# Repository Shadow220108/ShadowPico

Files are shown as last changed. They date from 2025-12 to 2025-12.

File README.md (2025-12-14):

# SHADOW PICO  
It is a handheld device that works on Raspberry Pi Pico

# Model  
This is the final look of the device  
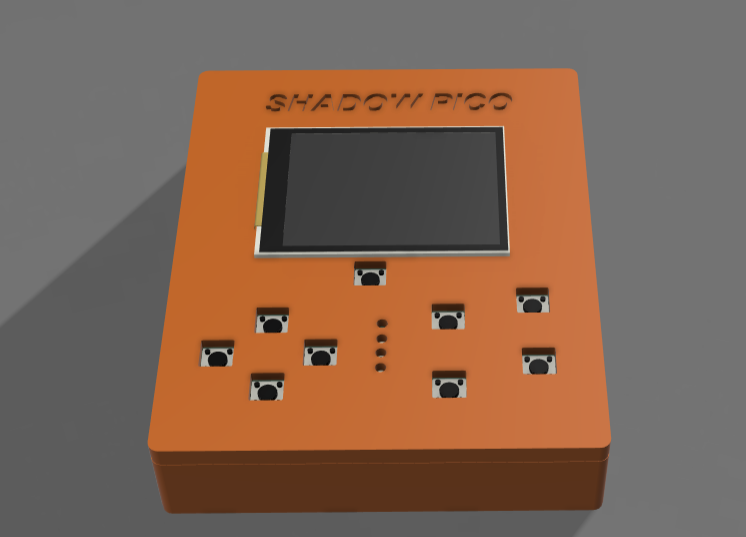
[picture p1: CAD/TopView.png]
TopView
  

I have added a small hole on the side for usb  
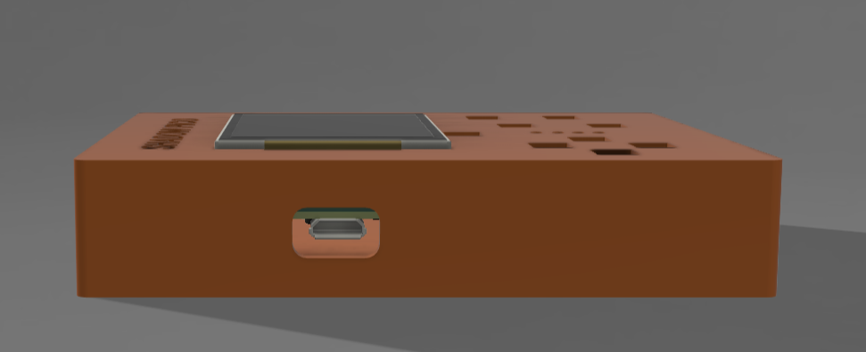
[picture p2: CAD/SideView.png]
SideView
  

On the front there are 3 holes for the SD Card , External Connector and a Slide switch for power  
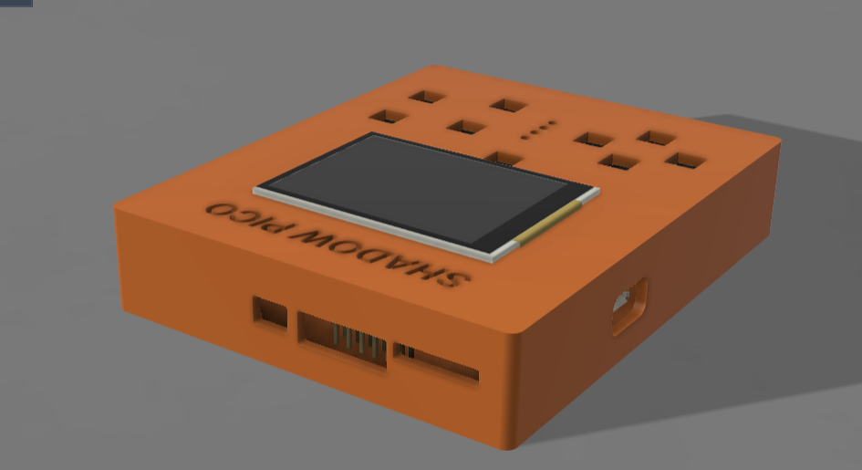
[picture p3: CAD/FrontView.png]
FrontView
  

I have used ridges to attach the bottom case to the top case!  
Bottom Case :  
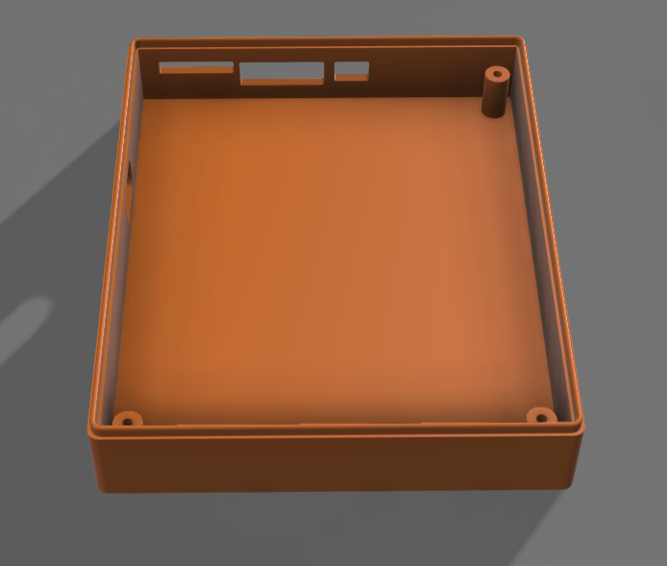
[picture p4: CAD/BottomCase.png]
BottomCase
  
Top Case :  
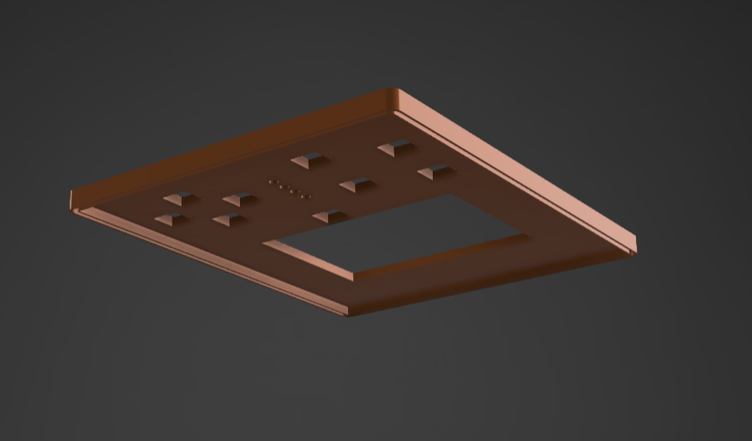
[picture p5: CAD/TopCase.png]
TopCase
  

# PCB  
This is the PCB ( ground pour is hidden )  
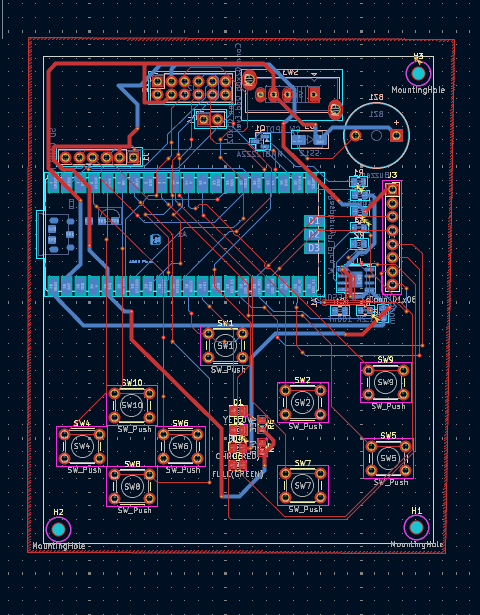
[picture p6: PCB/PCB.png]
PCB
  

And here are the schematics!  
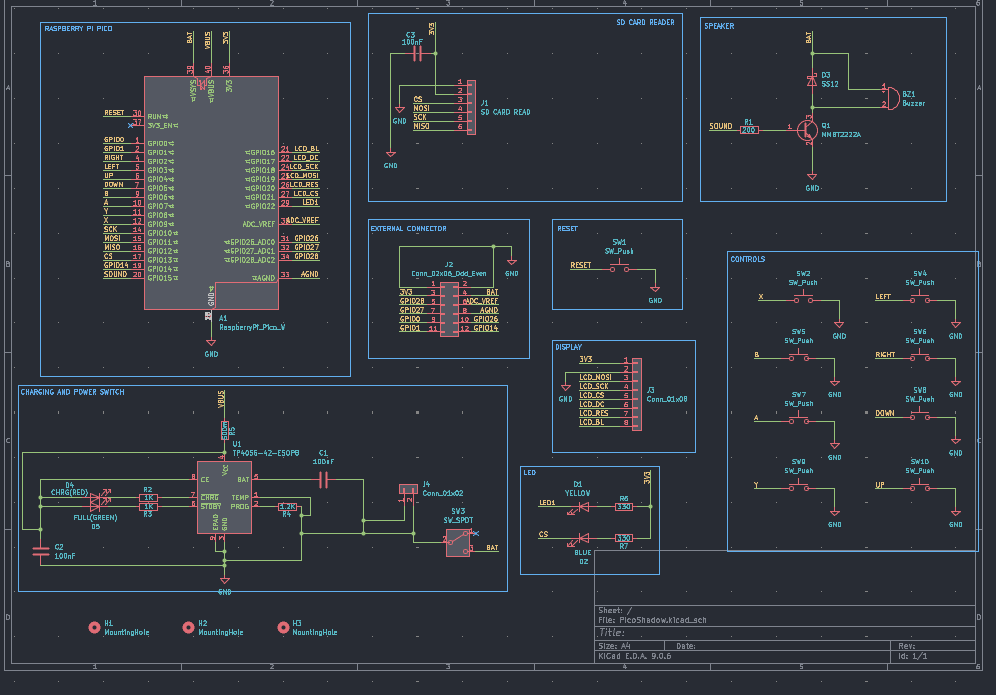
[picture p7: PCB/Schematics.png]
Schematics
  

# Firmware  
I have uploaded the basic code for arduino to identify buttons right now , will add the games after i get the card!  

# BOM  
|PRODUCT |QUANTITY  |PER UNIT COST|TOTAL COST |PRODUCT LINK |
|---|---|---|---|---|
| | | | | |
|Raspberry Pi Pico |1 |4$ |4$ |https://robu.in/product/raspberry-pi-pico/ |
| | | | | |
|Waveshare 2 inch LD |1 |10.40$ |14.40$ |https://robu.in/product/waveshare-2-inch-lcd-display-module-240x320/ |
| | | | | |
|TP4056 ( Charging IC )  |1 |0.13$ |14.53$ |https://robu.in/product/1-month-warranty-1253/ |
| | | | | |
|MMBT2222A ( Transistor )|1 |0.02$ |14.55$ |https://robu.in/product/mmbt2222a-tp-mcc-40v-350mw-100150ma10v-600ma-npn-sot-23-bipolar-bjt-rohs/ |
| | | | | |
|Diodes |3 |0.03$ |14.64$ |https://robu.in/product/ss12-slkor-20v-500mv1a-1a-smado-214ac-schottky-diodes-rohs/ |
| | | | | |
|Resistors |8 |0.03$ |14.88$ |https://robu.in/product/rt0805brd071kl-yageo-125mw-thin-film-resistor-150v-%c2%b125ppm-%e2%84%83-%c2%b10-1-1k%cf%89-0805-chip-resistor-surface-mount-rohs/ |
| | | | | |
|Capacitor |3 |0.01$ |14.91$ |https://robu.in/product/100nf-0805-surface-mount-multilayer-ceramic-capacitor-pack-of-40/ |
| | | | | |
|PCB |5(minimum)|2$ |25.67$ |https://jlpcb.com |
| | | | | |
|LED |4 |0.01$ |25.70$ |https://robu.in/product/0805-surface-mount-led-yellow/ |
| | | | | |
|Tactile Switches |10 |0.01$ |25.87$ |https://robu.in/product/6x6x5-tactile-push-button-switch/ |
| | | | | |
|Slide Switch |1 |0.07$ |26$ |https://robu.in/product/1-month-warranty-257/ |
| | | | | |
|External Header |1 |0.50$ |26.50$ |https://robu.in/product/ds1029-10-2x6p8bva1-b-connfly-2x6-pin-2-54mm-pin-header-double-row-stack-v-t-w-post-type/ |
| | | | | |
|Buzzer |1 |0.50$ |27$ |https://robu.in/product/1-month-warranty-1231/ |
| | | | | |
|LiPo Cell 3.7V Battery  |1 |4$ |31$ |https://robu.in/product/950mah-pcm-protected-micro-li-po-battery/ |
| | | | | |
|SD Card Reader |1 |0.50$ |31.50$ |https://robu.in/product/sd-card-reading-writing-module-arduino/#tab-questions |
| | | | | |
|SD Card |1 |3$ |34$ |https://www.flipkart.com/avoc-flash-mc016-microsdxc-16-gb-microsd-card-class-10-20-mb-s-memory-compatible-tablet-mobile-camera/p/itm6992565b2daec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|
| | | | | |
|3D Print | |3-4$ |38$ | |
| | | | | |
| | |TOTAL |40$ Approx!| |

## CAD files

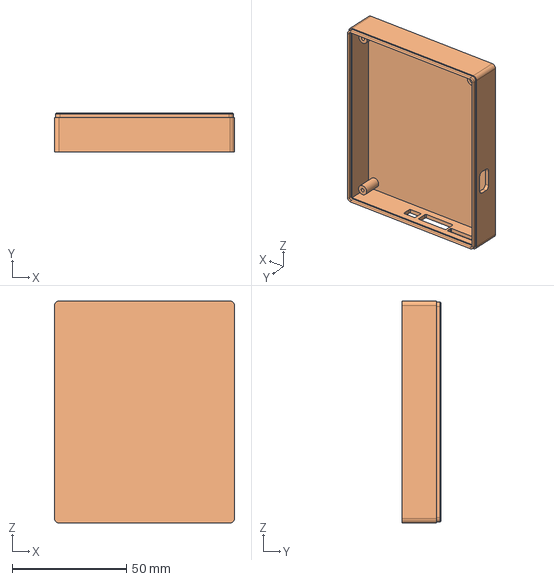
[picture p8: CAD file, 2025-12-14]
CAD/BottomCase.step
78.9 x 17.0 x 97.2 mm

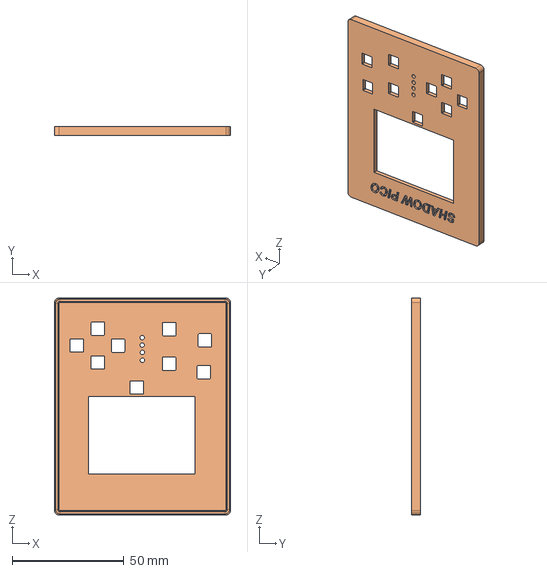
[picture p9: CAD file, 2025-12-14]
CAD/TopCase.step
78.9 x 4.00 x 97.2 mm

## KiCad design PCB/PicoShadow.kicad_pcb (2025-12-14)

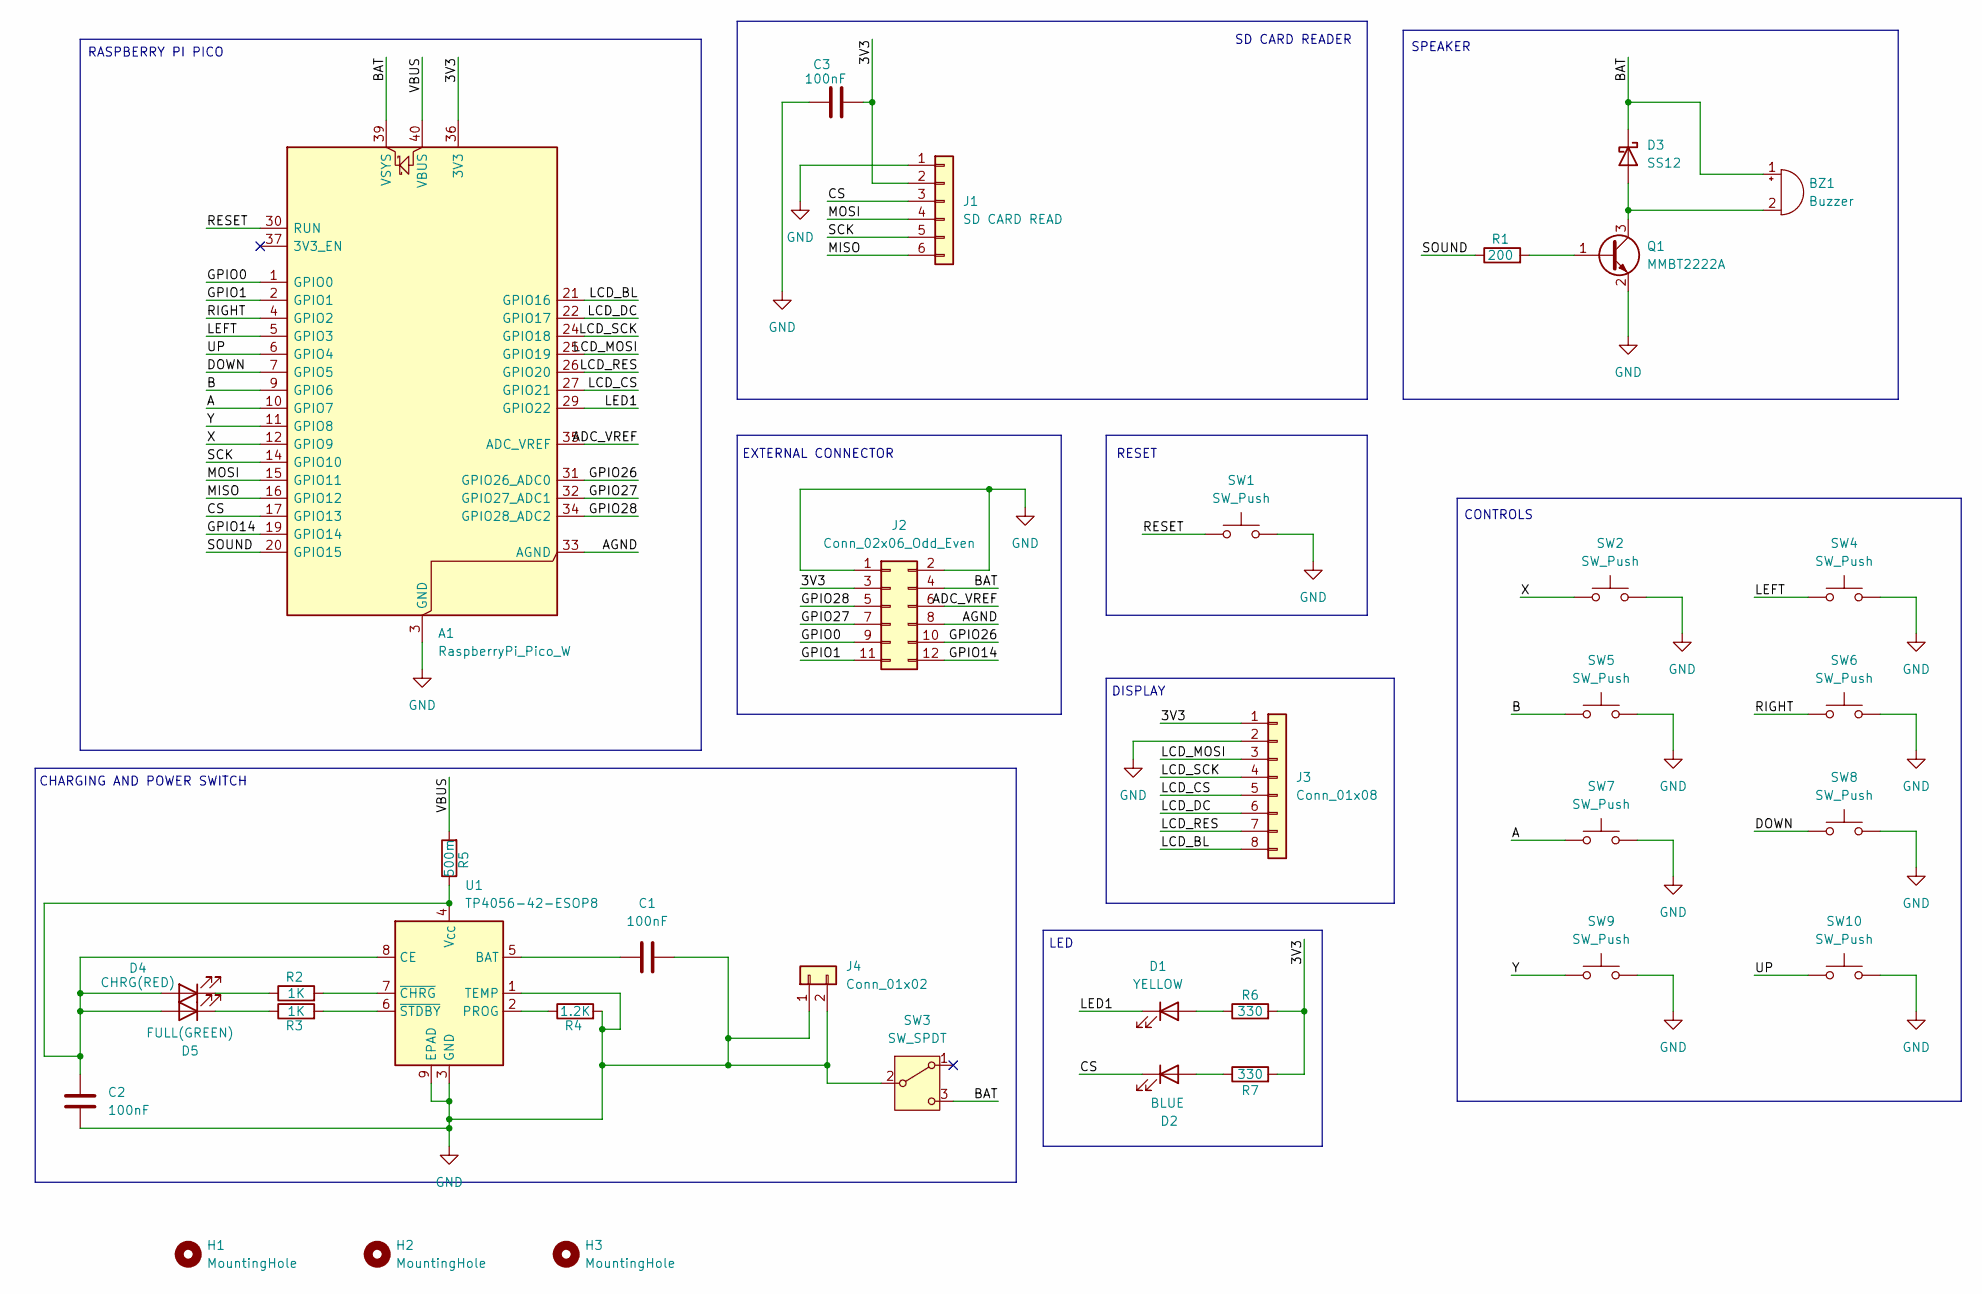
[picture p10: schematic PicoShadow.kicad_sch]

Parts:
A1: RaspberryPi_Pico_W; RaspberryPi_Pico_SMD
BZ1: Buzzer; Buzzer_12x9.5RM7.6
C1, C2, C3: 100nF; C_0805_2012Metric
D1: YELLOW; LED_0805_2012Metric
D2: BLUE; LED_0805_2012Metric
D3: SS12; D_SMA
D4: CHRG(RED); LED_0805_2012Metric
D5: FULL(GREEN); LED_0805_2012Metric
H1, H2, H3: MountingHole; MountingHole_2.2mm_M2
J1: SD CARD READ; PinHeader_1x06_P2.54mm_Vertical
J2: Conn_02x06_Odd_Even; PinHeader_2x06_P2.54mm_Vertical
J3: Conn_01x08; PinSocket_1x08_P2.54mm_Vertical
J4: Conn_01x02; PinHeader_1x02_P2.54mm_Vertical
Q1: MMBT2222A; SOT-23
R1: 200; R_0805_2012Metric
R2, R3: 1K; R_0805_2012Metric
R4: 1.2K; R_0805_2012Metric
R5: 500m; R_0805_2012Metric
R6, R7: 330; R_0805_2012Metric
SW1, SW2, SW4, SW5, SW6, SW7, SW8, SW9, SW10: SW_Push; SW_PUSH_6mm
SW3: SW_SPDT; SW_Slide_SP3T_Straight_CK_OS103012MU1QP1
U1: TP4056-42-ESOP8; SOIC-8-1EP_3.9x4.9mm_P1.27mm_EP2.29x3mm

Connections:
/3V3: A1.36 (3V3), C3.2, J1.2, J2.3, J3.1, R6.2, R7.2
/A: A1.10 (GPIO7), SW7.1
/ADC_VREF: A1.35 (ADC_VREF), J2.6
/AGND: A1.33 (AGND), J2.8
/B: A1.9 (GPIO6), SW5.1
/BAT: A1.39 (VSYS), BZ1.1 (+), D3.1 (K), J2.4, SW3.3 (C)
/CS: A1.17 (GPIO13), D2.1 (K), J1.3
/DOWN: A1.7 (GPIO5), SW8.1
/GPIO0: A1.1 (GPIO0), J2.9
/GPIO1: A1.2 (GPIO1), J2.11
/GPIO14: A1.19 (GPIO14), J2.12
/GPIO26: A1.31 (GPIO26_ADC0), J2.10
/GPIO27: A1.32 (GPIO27_ADC1), J2.7
/GPIO28: A1.34 (GPIO28_ADC2), J2.5
/LCD_BL: A1.21 (GPIO16), J3.8
/LCD_CS: A1.27 (GPIO21), J3.5
/LCD_DC: A1.22 (GPIO17), J3.6
/LCD_MOSI: A1.25 (GPIO19), J3.3
/LCD_RES: A1.26 (GPIO20), J3.7
/LCD_SCK: A1.24 (GPIO18), J3.4
/LED1: A1.29 (GPIO22), D1.1 (K)
/LEFT: A1.5 (GPIO3), SW4.1
/MISO: A1.16 (GPIO12), J1.6
/MOSI: A1.15 (GPIO11), J1.4
/RESET: A1.30 (RUN), SW1.1
/RIGHT: A1.4 (GPIO2), SW6.1
/SCK: A1.14 (GPIO10), J1.5
/SOUND: A1.20 (GPIO15), R1.1
/UP: A1.6 (GPIO4), SW10.1
/VBUS: A1.40 (VBUS), R5.2
/X: A1.12 (GPIO9), SW2.1
/Y: A1.11 (GPIO8), SW9.1
GND: A1.3 (GND), A1.8 (GND), A1.13 (GND), A1.18 (GND), A1.23 (GND), A1.28 (GND), A1.38 (GND), C1.2, C2.2, C3.1, J1.1, J2.1, J2.2, J3.2, J4.1, J4.2, Q1.2 (E), R4.2, SW1.2, SW2.2, SW3.2 (B), SW4.2, SW5.2, SW6.2, SW7.2, SW8.2, SW9.2, SW10.2, U1.1 (TEMP), U1.3 (GND), U1.9 (EPAD)
unnamed: BZ1.2 (-), D3.2 (A), Q1.3 (C)
unnamed: D1.2 (A), R6.1
unnamed: D2.2 (A), R7.1
unnamed: C2.1, D4.2 (A), D5.2 (A), R5.1, U1.4 (V_{CC}), U1.8 (CE)
unnamed: D4.1 (K), R2.1
unnamed: D5.1 (K), R3.1
unnamed: Q1.1 (B), R1.2
unnamed: C1.1, U1.5 (BAT)
unnamed: R4.1, U1.2 (PROG)
unnamed: R2.2, U1.7 (~CHRG)
unnamed: R3.2, U1.6 (~STDBY)

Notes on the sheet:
CONTROLS
RASPBERRY PI PICO
SPEAKER
RESET
SD CARD READER
DISPLAY
CHARGING AND POWER SWITCH
LED
EXTERNAL CONNECTOR

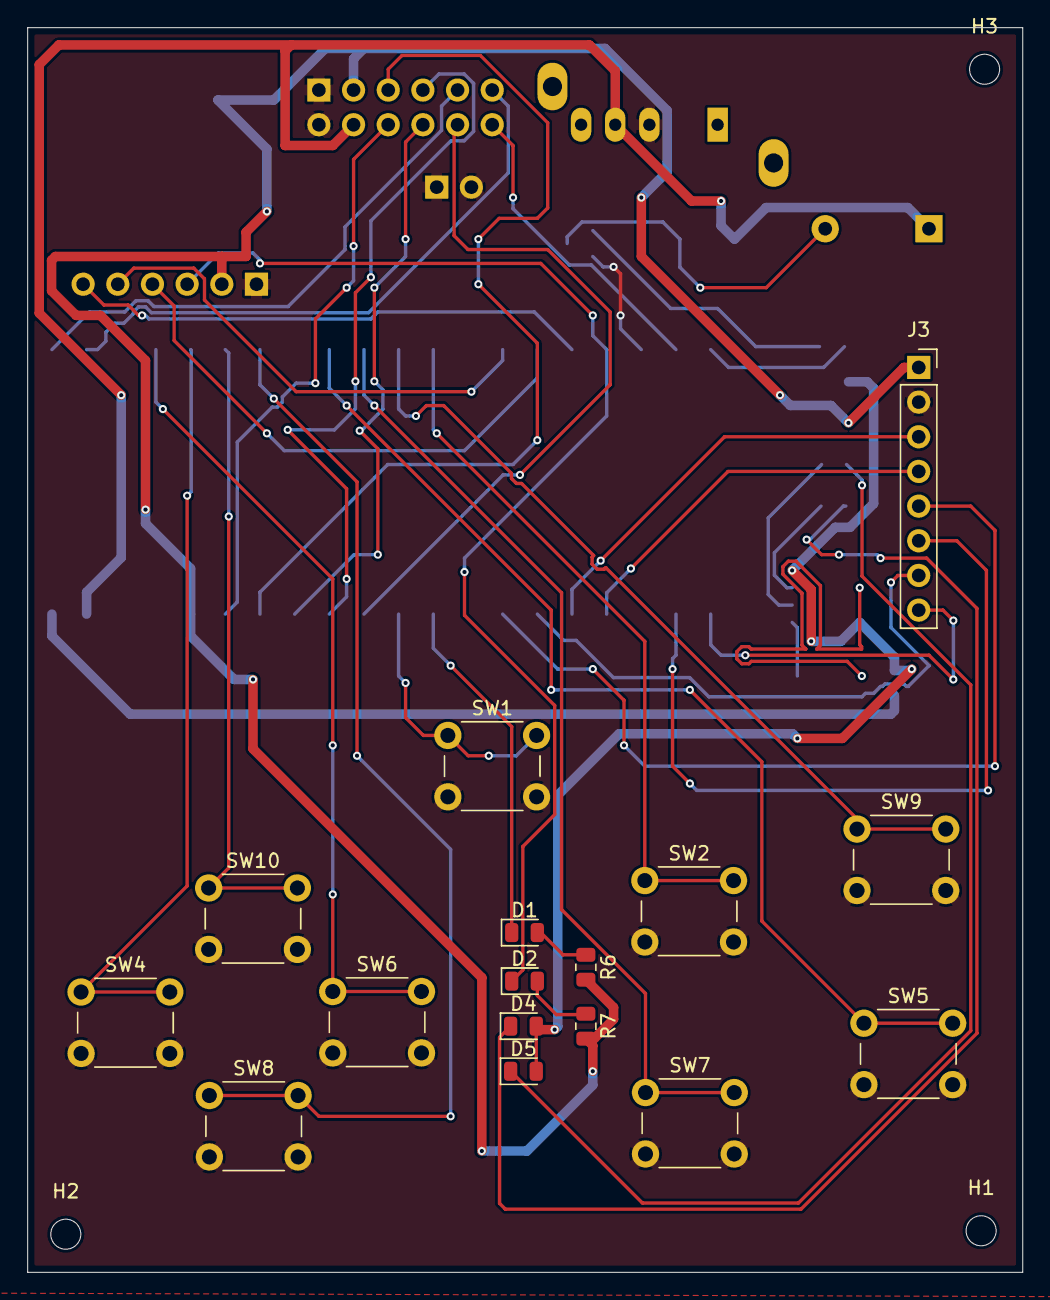
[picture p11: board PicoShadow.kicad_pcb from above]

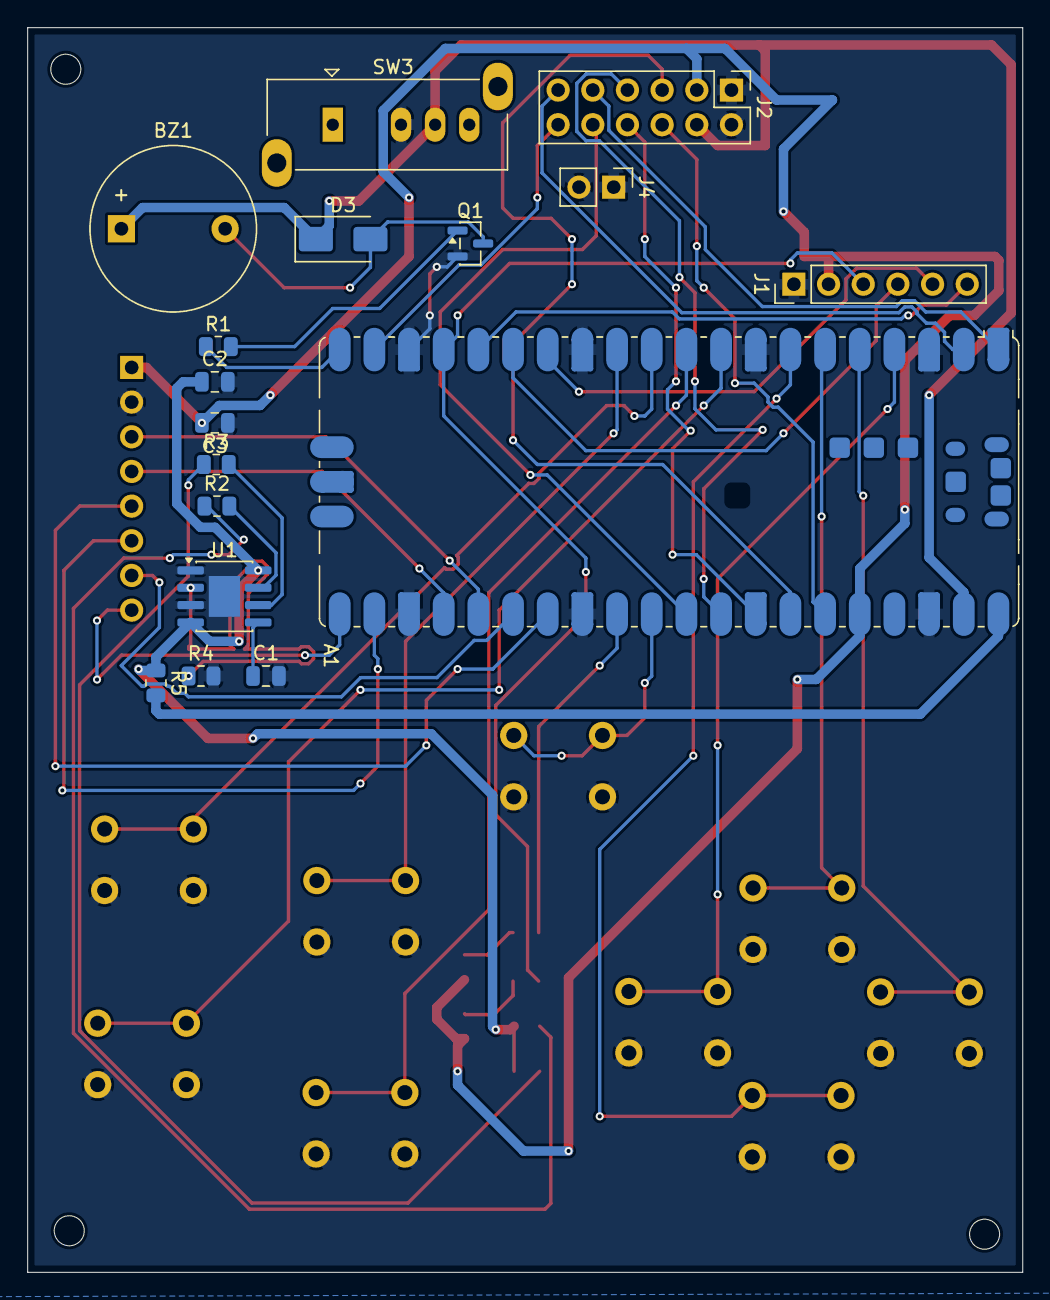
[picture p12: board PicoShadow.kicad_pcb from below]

Board: 2 copper layers, 72.9 x 91.2 mm, 36 parts (17 on the bottom side), 44 nets.

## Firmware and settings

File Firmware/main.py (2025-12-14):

from machine import Pin, PWM
import utime

btn_up = Pin(4, Pin.IN, Pin.PULL_UP)
btn_down = Pin(5, Pin.IN, Pin.PULL_UP)
btn_left = Pin(3, Pin.IN, Pin.PULL_UP)
btn_right = Pin(2, Pin.IN, Pin.PULL_UP)

btn_a = Pin(7, Pin.IN, Pin.PULL_UP)
btn_b = Pin(6, Pin.IN, Pin.PULL_UP)
btn_x = Pin(9, Pin.IN, Pin.PULL_UP)
btn_y = Pin(8, Pin.IN, Pin.PULL_UP)

led_user = Pin(22, Pin.OUT)
buzzer = Pin(15, Pin.OUT)


def beep(duration_ms):
    buzzer.value(1)
    led_user.value(1)
    utime.sleep_ms(duration_ms)
    buzzer.value(0)
    led_user.value(0)


print("--- CYBERDECK SYSTEM START ---")
print("Press any button to test...")

beep(50)
utime.sleep_ms(100)
beep(50)

while True:
    if btn_up.value() == 0:
        print("UP Pressed")
        beep(20)
        while btn_up.value() == 0: pass

    if btn_down.value() == 0:
        print("DOWN Pressed")
        beep(20)
        while btn_down.value() == 0: pass

    if btn_left.value() == 0:
        print("LEFT Pressed")
        beep(20)
        while btn_left.value() == 0: pass

    if btn_right.value() == 0:
        print("RIGHT Pressed")
        beep(20)
        while btn_right.value() == 0: pass

    if btn_a.value() == 0:
        print("A Button Pressed")
        beep(50)
        while btn_a.value() == 0: pass

    if btn_b.value() == 0:
        print("B Button Pressed")
        beep(50)
        while btn_b.value() == 0: pass

    if btn_x.value() == 0:
        print("X Button Pressed")
        beep(50)
        while btn_x.value() == 0: pass

    if btn_y.value() == 0:
        print("Y Button Pressed")
        beep(50)
        while btn_y.value() == 0: pass

    utime.sleep_ms(10)
